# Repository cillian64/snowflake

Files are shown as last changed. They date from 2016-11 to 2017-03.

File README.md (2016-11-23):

# Snowflake: David's "Yuletronics" project.

A christmas decoration shaped like a snowflake, with beautiful white LEDs.
Also the most ridiculously shaped PCB I've ever had made.

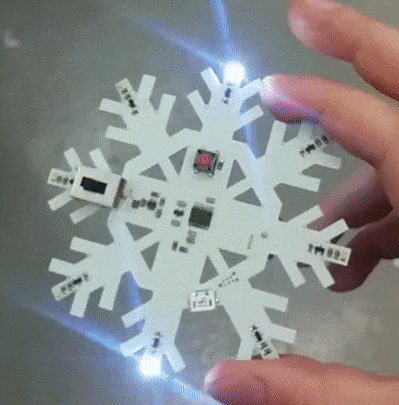
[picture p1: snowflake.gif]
snowflake animation


Uses the TI TLV61220 boost SMPS controller to generate 5V from a single
alkaline cell.  Alternatively powered via MicroUSB-B.  Controlled by STM32F042,
programmed using TagConnect SWD or USB DFU.

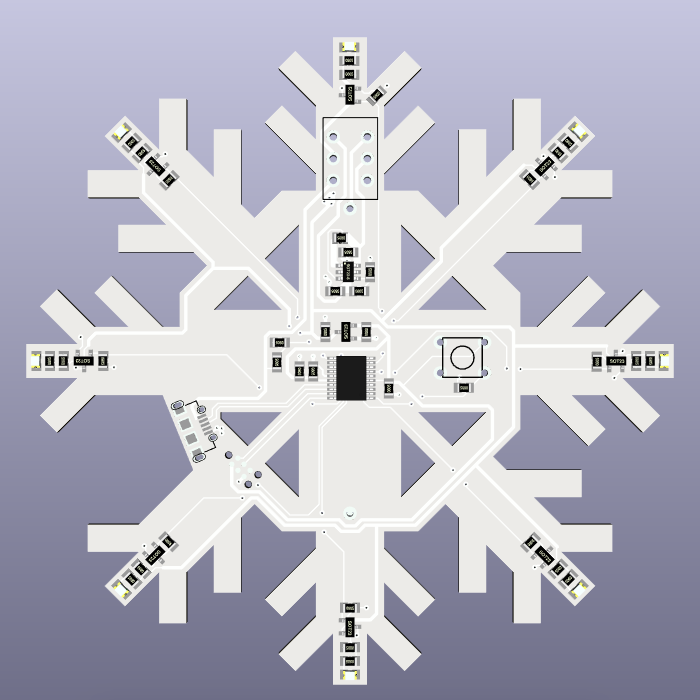
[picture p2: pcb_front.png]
PCB front


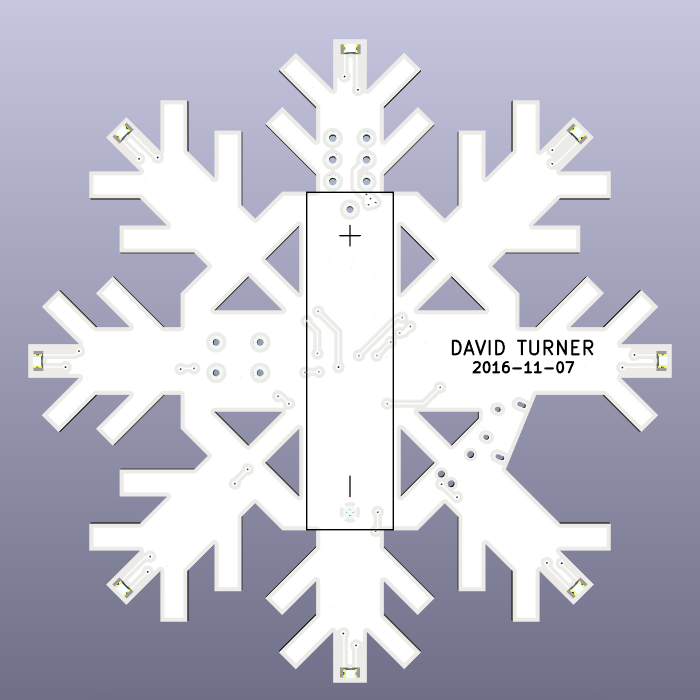
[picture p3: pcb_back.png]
PCB back


Based on [Adam Greig's Christmas
Tree](https://github.com/adamgreig/yuletronics/)

Made in [KiCAD 4.0.4](http://kicad-pcb.org/).

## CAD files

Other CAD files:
pcb/gerbers/yuletronics-F.Paste.dxf

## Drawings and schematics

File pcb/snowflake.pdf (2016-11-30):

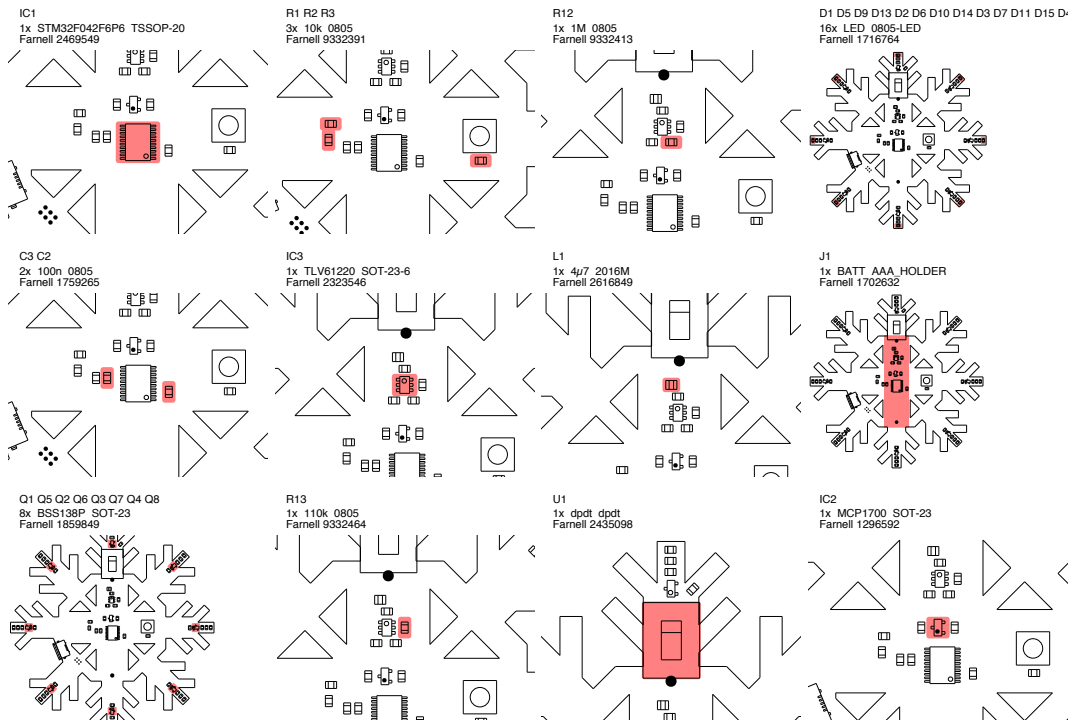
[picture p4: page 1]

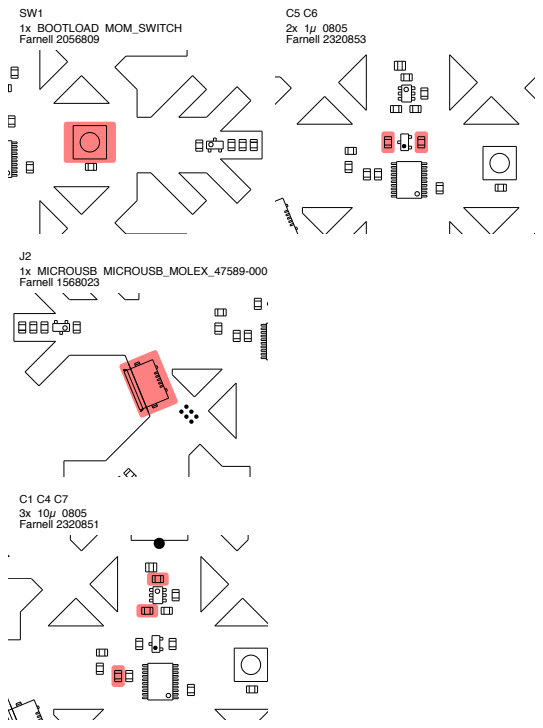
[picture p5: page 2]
SW1 1x BOOTLOAD MOM_SWITCH Farnell 2056809; J2 1x MICROUSB MICROUSB_MOLEX_47589-0001 Farnell 1568023; C1 C4 C7 3x 10µ 0805 Farnell 2320851; C5 C6 2x 1µ 0805 Farnell 2320853

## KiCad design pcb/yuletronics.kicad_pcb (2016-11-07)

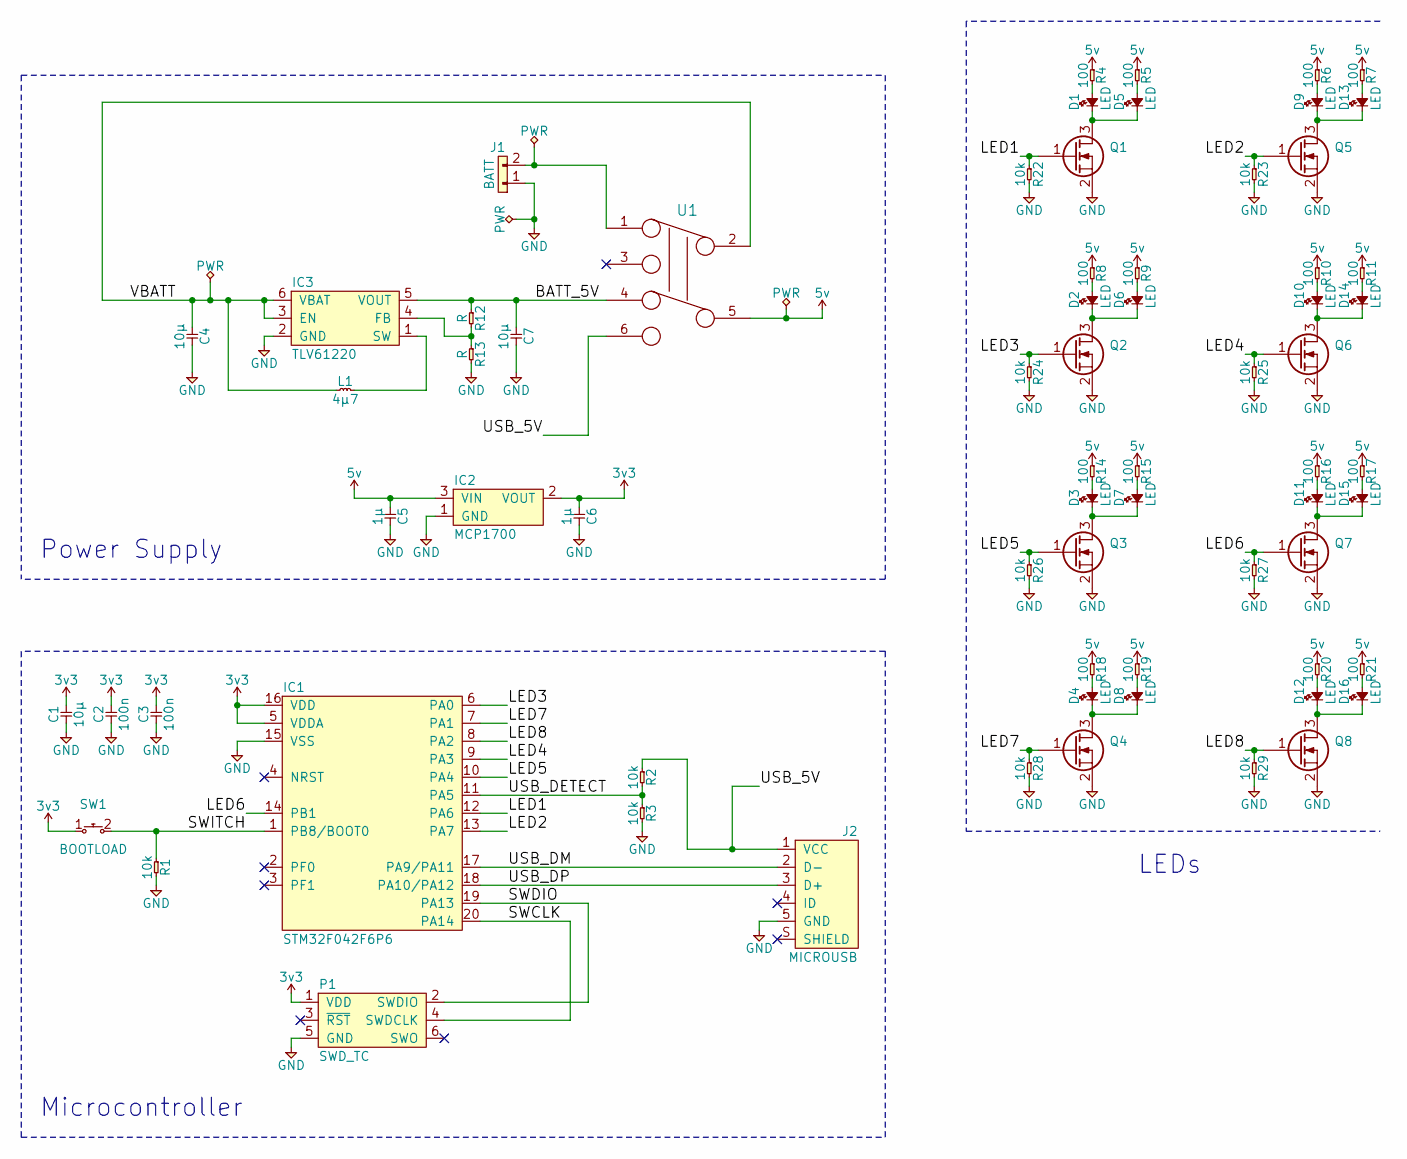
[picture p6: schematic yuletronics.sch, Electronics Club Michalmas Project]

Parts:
C1, C4, C7: 10µ; 0805; Farnell 2320851
C2, C3: 100n; 0805; Farnell 1759265
C5, C6: 1µ; 0805; Farnell 2320853
D1, D2, D3, D4, D5, D6, D7, D8, D9, D10, D11, D12, D13, D14, D15, D16: LED; 0805-LED; Farnell 1716764
IC1: STM32F042F6P6; TSSOP-20; Farnell 2469549
IC2: MCP1700; SOT-23; Farnell 1296592
IC3: TLV61220; SOT-23-6; Farnell 2323546
J1: BATT; AAA_HOLDER; Farnell 1702632
J2: MICROUSB; MICROUSB_MOLEX_47589-0001; Farnell 1568023
L1: 4µ7; 2016M; Farnell 2616849
P1: SWD_TC; TC2030-NL
Q1, Q2, Q3, Q4, Q5, Q6, Q7, Q8: BSS138P; SOT-23; Farnell 1859849
R1, R2, R3: 10k; 0805; Farnell 9332391
R4, R5, R6, R7, R8, R9, R10, R11, R14, R15, R16, R17, R18, R19, R20, R21: 100; 0805
R12, R13: R; 0805
R22, R23, R24, R25, R26, R27, R28, R29: 10k; 0805
SW1: BOOTLOAD; MOM_SWITCH; Farnell 2056809
U1: dpdt; Farnell 2435098

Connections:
3v3: C1.2, C2.2, C3.2, C6.1, IC1.5 (VDDA), IC1.16 (VDD), IC2.2 (VOUT), P1.1 (VDD), SW1.1
5v: C5.1, IC2.3 (VIN), R4.1, R5.1, R6.1, R7.1, R8.1, R9.1, R10.1, R11.1, R14.1, R15.1, R16.1, R17.1, R18.1, R19.1, R20.1, R21.1, U1.5
/BATT_5V: C7.1, IC3.5 (VOUT), R12.1, U1.4
/LED1: IC1.12 (PA6), Q1.1 (G), R22.1
/LED2: IC1.13 (PA7), Q5.1 (G), R23.1
/LED3: IC1.6 (PA0), Q2.1 (G), R24.1
/LED4: IC1.9 (PA3), Q6.1 (G), R25.1
/LED5: IC1.10 (PA4), Q3.1 (G), R26.1
/LED6: IC1.14 (PB1), Q7.1 (G), R27.1
/LED7: IC1.7 (PA1), Q4.1 (G), R28.1
/LED8: IC1.8 (PA2), Q8.1 (G), R29.1
/SWCLK: IC1.20 (PA14), P1.4 (SWDCLK)
/SWDIO: IC1.19 (PA13), P1.2 (SWDIO)
/SWITCH: IC1.1 (PB8/BOOT0), R1.1, SW1.2
/USB_5V: J2.1 (VCC), R2.1, U1.6
/USB_DETECT: IC1.11 (PA5), R2.2, R3.1
/USB_DM: IC1.17 (PA9/PA11), J2.2 (D-)
/USB_DP: IC1.18 (PA10/PA12), J2.3 (D+)
/VBATT: C4.1, IC3.3 (EN), IC3.6 (VBAT), L1.1, U1.2
GND: C1.1, C2.1, C3.1, C4.2, C5.2, C6.2, C7.2, IC1.15 (VSS), IC2.1 (GND), IC3.2 (GND), J1.1, J2.5 (GND), P1.5 (GND), Q1.2 (S), Q2.2 (S), Q3.2 (S), Q4.2 (S), Q5.2 (S), Q6.2 (S), Q7.2 (S), Q8.2 (S), R1.2, R3.2, R13.2, R22.2, R23.2, R24.2, R25.2, R26.2, R27.2, R28.2, R29.2
unnamed: D1.1, D5.1, Q1.3 (D)
unnamed: D1.2, R4.2
unnamed: D2.1, D6.1, Q2.3 (D)
unnamed: D2.2, R8.2
unnamed: D3.1, D7.1, Q3.3 (D)
unnamed: D3.2, R14.2
unnamed: D4.1, D8.1, Q4.3 (D)
unnamed: D4.2, R18.2
unnamed: D5.2, R5.2
unnamed: D6.2, R9.2
unnamed: D7.2, R15.2
unnamed: D8.2, R19.2
unnamed: D9.2, R6.2
unnamed: D10.1, D14.1, Q6.3 (D)
unnamed: D10.2, R10.2
unnamed: D11.1, D15.1, Q7.3 (D)
unnamed: D11.2, R16.2
unnamed: D12.1, D16.1, Q8.3 (D)
unnamed: D12.2, R20.2
unnamed: D9.1, D13.1, Q5.3 (D)
unnamed: D13.2, R7.2
unnamed: D14.2, R11.2
unnamed: D15.2, R17.2
unnamed: D16.2, R21.2
unnamed: IC3.1 (SW), L1.2
unnamed: IC3.4 (FB), R12.2, R13.1
unnamed: J1.2, U1.1

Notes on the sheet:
Power Supply
Microcontroller
LEDs

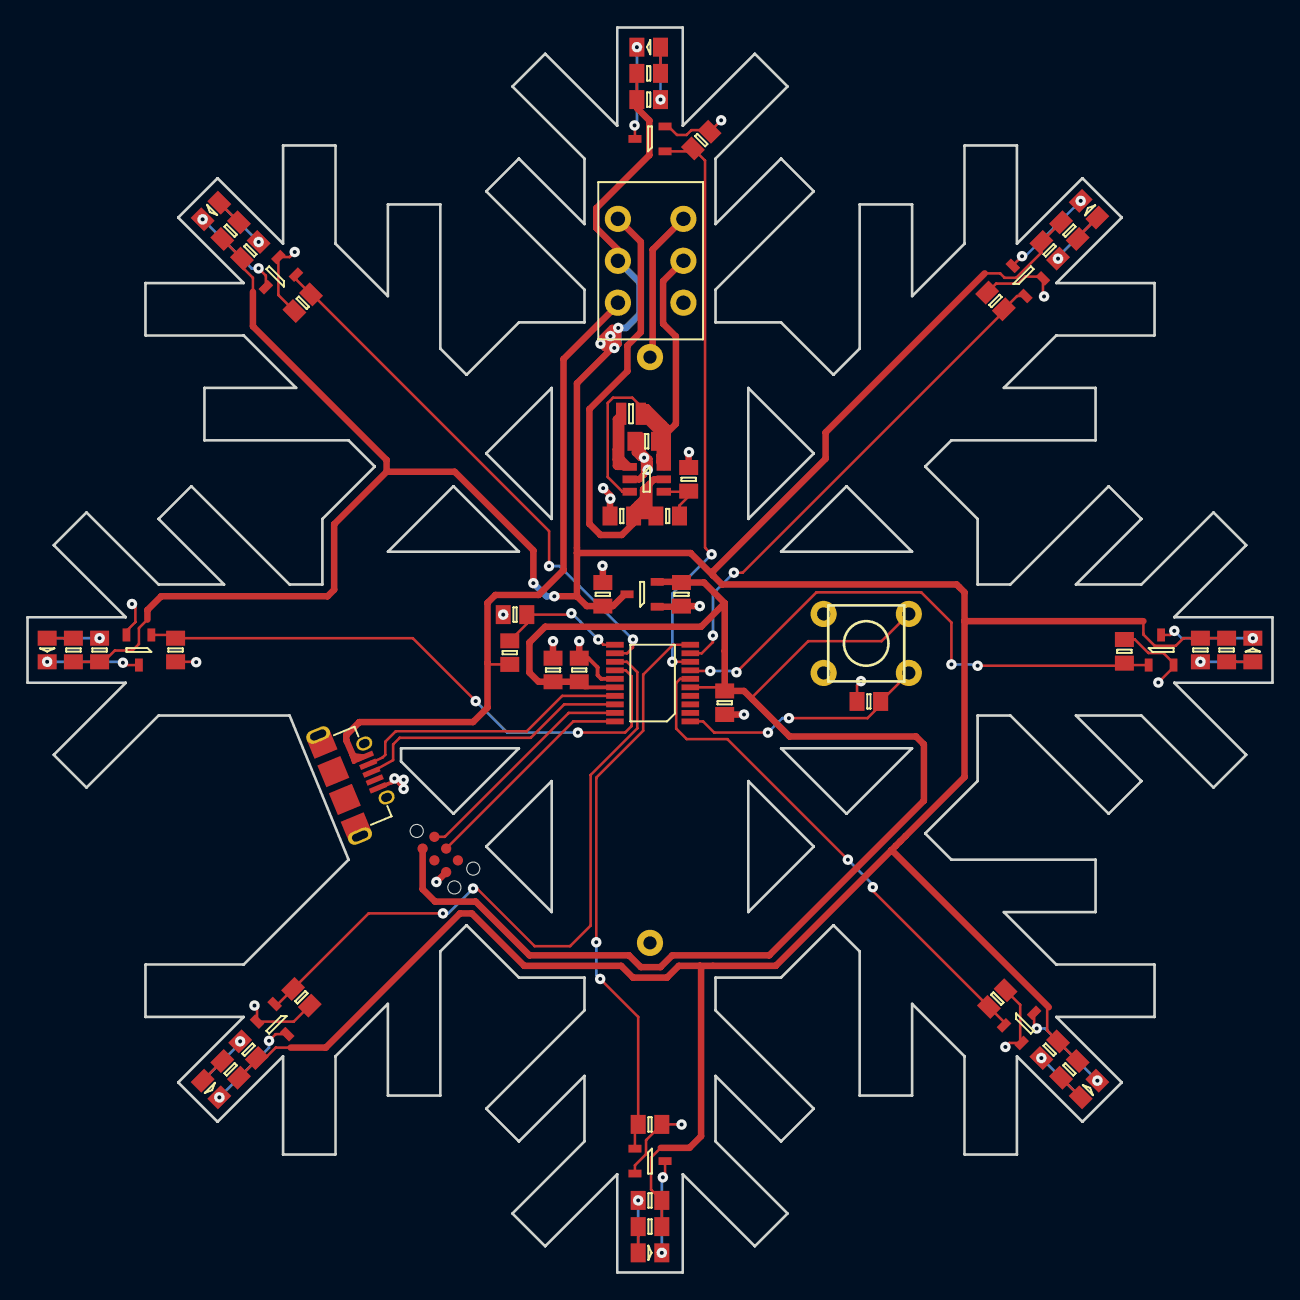
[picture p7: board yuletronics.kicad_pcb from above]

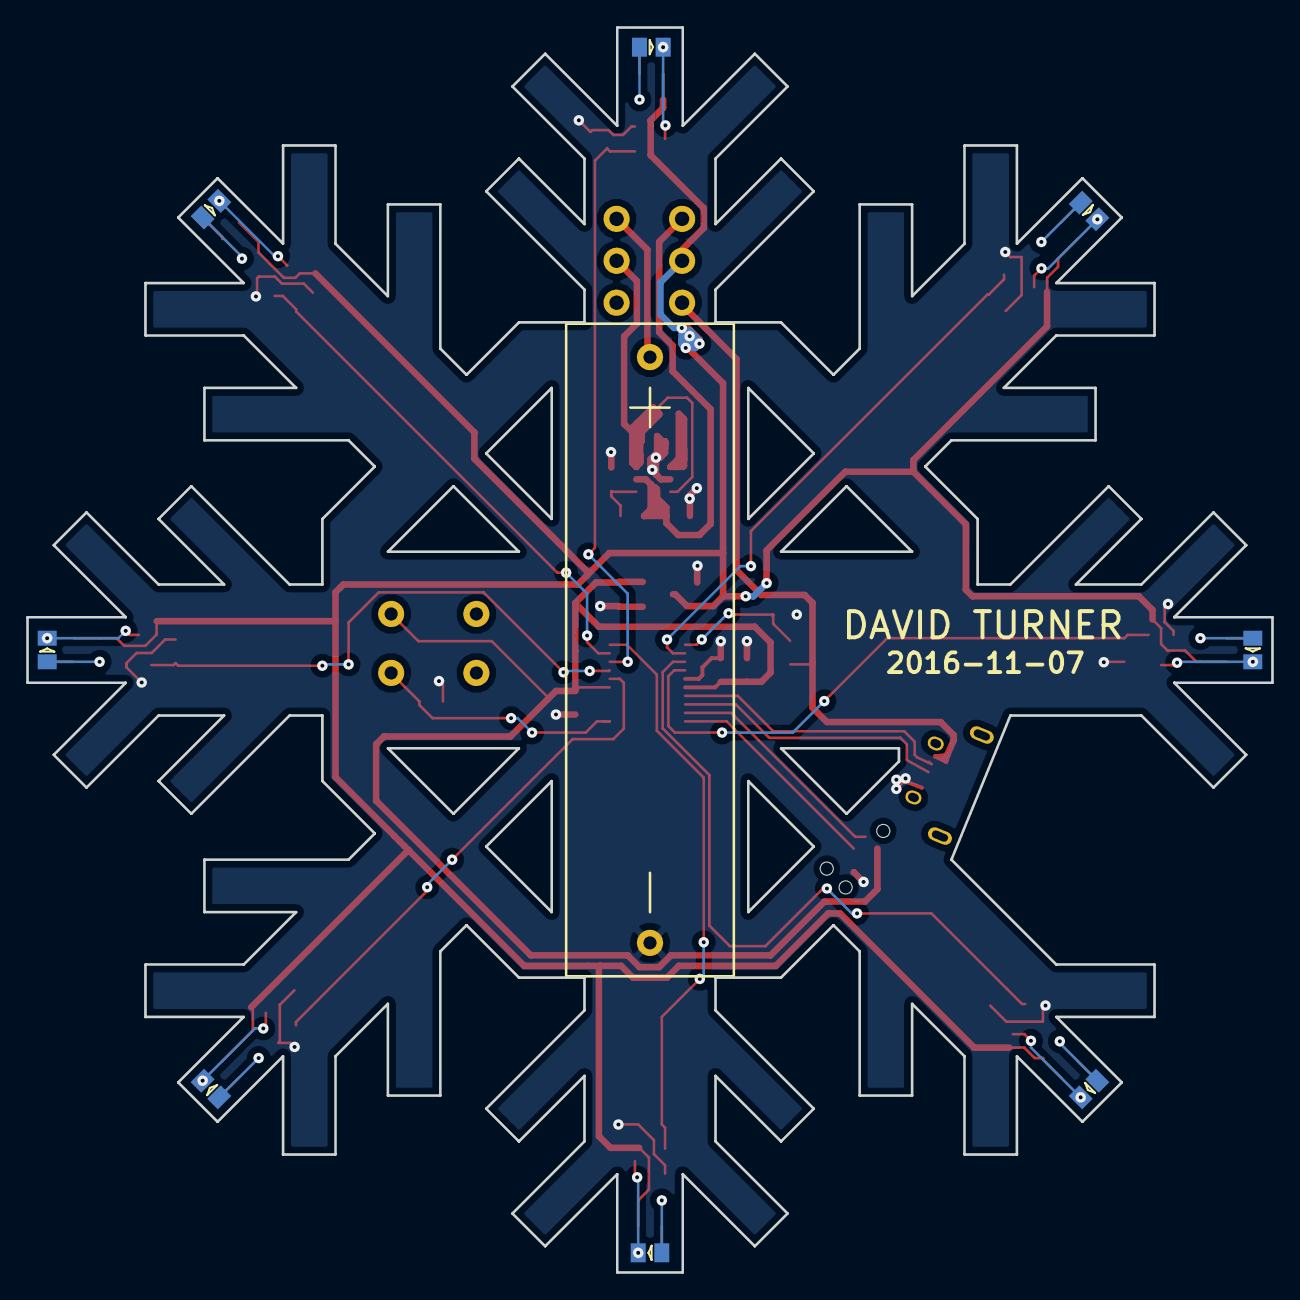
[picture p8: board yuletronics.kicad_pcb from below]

Board: 2 copper layers, 95.0 x 95.0 mm, 69 parts (9 on the bottom side), 47 nets.

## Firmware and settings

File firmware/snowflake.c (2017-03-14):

#include <stdint.h>
#include <stdbool.h>

#include <libopencm3/cm3/nvic.h>
#include <libopencm3/stm32/rcc.h>
#include <libopencm3/stm32/gpio.h>
#include <libopencm3/stm32/timer.h>
#include <libopencm3/stm32/pwr.h>
#include <libopencm3/stm32/iwdg.h>

#define LED1 GPIO0
#define LED2 GPIO1
#define LED3 GPIO2
#define LED4 GPIO3
#define LED5 GPIO4
#define LED6 GPIO6
#define LED7 GPIO7
#define LED8 GPIO1

#define LED1_PORT GPIOA
#define LED2_PORT GPIOA
#define LED3_PORT GPIOA
#define LED4_PORT GPIOA
#define LED5_PORT GPIOA
#define LED6_PORT GPIOA
#define LED7_PORT GPIOA
#define LED8_PORT GPIOB

static const uint16_t led_pins[] = {
    0,
    LED1, LED2, LED3, LED4, LED5, LED6, LED7, LED8
};

static const uint32_t led_ports[] = {
    0,
    LED1_PORT, LED2_PORT, LED3_PORT, LED4_PORT,
    LED5_PORT, LED6_PORT, LED7_PORT, LED8_PORT
};

#define TURNON(led) gpio_set(led_ports[led], led_pins[led])
#define TURNOFF(led) gpio_clear(led_ports[led], led_pins[led])

//#define RTC_BKP0R MMIO32(RTC_BASE + 0x50)
#define RTC_BKP0R MMIO32(0x40002860)

#define SCB_SCR MMIO32(SCB_BASE + 0x10)
#define SCB_SCR_SLEEPDEEP (1<<2)

static void gpio_setup(void)
{
    int led;

    rcc_periph_clock_enable(RCC_GPIOA);
    rcc_periph_clock_enable(RCC_GPIOB);

    for(led=1; led<=8; led++) {
        gpio_clear(led_ports[led], led_pins[led]);
        gpio_mode_setup(
            led_ports[led], GPIO_MODE_OUTPUT, GPIO_PUPD_NONE, led_pins[led]);
        gpio_set_output_options(
            led_ports[led], GPIO_OTYPE_PP, GPIO_OSPEED_LOW, led_pins[led]);
    }
}

void tim14_isr(void)
{
    // Clear interrupt flag
    TIM_SR(TIM14) &= ~TIM_SR_UIF;
}

static void shortwait(void)
{
    // About 0.25ms
    timer_set_period(TIM14, 1);
    timer_enable_counter(TIM14);
    SCB_SCR &= ~SCB_SCR_SLEEPDEEP;
    __asm__("wfi");
    timer_disable_counter(TIM14);
}

static void standby(void)
{
    SCB_SCR |= SCB_SCR_SLEEPDEEP;
    pwr_set_standby_mode();
    __asm__("wfi");
}

int main(void)
{
    gpio_setup();

    // Setup TIM14 for sleep wakeups
    rcc_periph_clock_enable(RCC_TIM14);
    timer_reset(TIM2);
    timer_set_mode(TIM14, TIM_CR1_CKD_CK_INT, TIM_CR1_CMS_EDGE,
                   TIM_CR1_DIR_UP);
    // PCLK is running at 8MHz from HSI
    // Prescaler: divide by 2000 for timer at ~4kHz
    timer_set_prescaler(TIM14, 1999u);
    nvic_enable_irq(NVIC_TIM14_IRQ);
    timer_enable_irq(TIM14, TIM_DIER_UIE);
    timer_enable_update_event(TIM14);
    timer_disable_counter(TIM14);

    rcc_periph_clock_enable(RCC_PWR);
    rcc_periph_clock_enable(RCC_RTC);
    pwr_disable_backup_domain_write_protect();

    iwdg_reset();

    if(RTC_BKP0R > 7)
        RTC_BKP0R = 0;

    switch(RTC_BKP0R)
    {
        case 0:
            TURNON(1);
            shortwait();
            TURNOFF(1);
            break;
        case 1:
            TURNON(4);
            shortwait();
            TURNOFF(4);
            break;
        case 2:
            TURNON(6);
            shortwait();
            TURNOFF(6);
            break;
        case 3:
            TURNON(2);
            shortwait();
            TURNOFF(2);
            break;
        case 4:
            TURNON(8);
            shortwait();
            TURNOFF(8);
            break;
        case 5:
            TURNON(5);
            shortwait();
            TURNOFF(5);
            break;
        case 6:
            TURNON(7);
            shortwait();
            TURNOFF(7);
            break;
        case 7:
            TURNON(3);
            shortwait();
            TURNOFF(3);
            break;
    }

    RTC_BKP0R += 1;
    if(RTC_BKP0R == 8)
        RTC_BKP0R = 0;

    iwdg_reset();
    iwdg_set_period_ms(100);
    iwdg_start();
    standby();

    return 0;
}

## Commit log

2016-10-20 More LEDs, MOSFETs, board outline
    [yuletronics.kicad_pcb, yuletronics.sch]
2016-11-02 Partially did new 5V bus
    [yuletronics.kicad_pcb, yuletronics.sch]
2016-11-02 Added FET pulldowns, placed and routed
    [yuletronics.kicad_pcb, yuletronics.sch]
2016-11-07 Moved resistors to front, LEDs to edge
    [yuletronics.kicad_pcb, yuletronics.sch]
2016-11-07 updated gerber zip
2016-11-07 Changed edge cuts to add space for usb connector
    [yuletronics-B.Cu.gbl, yuletronics-B.Mask.gbs, yuletronics-B.SilkS.gbo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]
2016-11-23 Added stencil, SMPS R values/parts
    [yuletronics-F.Paste.dxf, yuletronics.sch]
2016-11-23 pcb renders
2016-12-02 increased led hold time for bolder flash
2016-12-05 Updated BOM
    [yuletronics.sch]
2016-12-17 New low power mode
2016-12-17 Even lower power mode using standby
2016-12-23 Removed switches and USB
    [yuletronics.sch]
2016-12-23 Changed uc to STM32F030F4 TSSOP20
    [yuletronics.sch]
2017-03-13 snowflake BOM
